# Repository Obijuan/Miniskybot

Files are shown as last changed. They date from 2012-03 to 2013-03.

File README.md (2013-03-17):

Miniskybot V2
===============

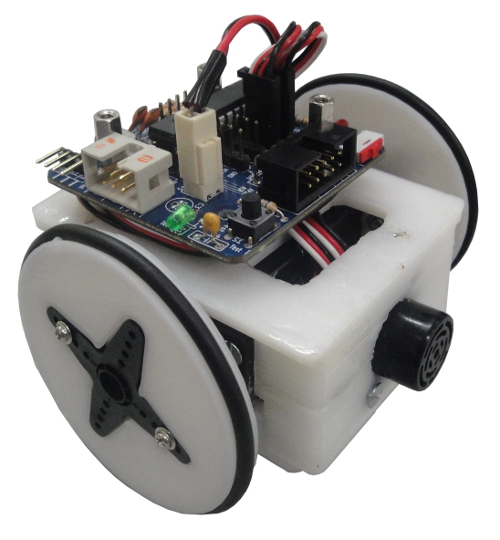
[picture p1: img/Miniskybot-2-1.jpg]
Miniskybot V2 with an skymega board Title


An open source 3D printable mobile robot ( **printbot** )

In this repository you can find the Miniskybot 2 or later
You can find more information (in spanish) in [this page](http://www.iearobotics.com/wiki/index.php?title=Miniskybot_2)

Features
--------
* Simplified chassis
* Marbel as cator wheel (thanks to sliptonic)
* Battery holder screwed to the chassis
* Compact and small
* 3 type of wheels, for the 3 different servo horns
* Electronics Compatible with [skymega](http://www.thingiverse.com/thing:14197) and [Arduino UNO](http://arduino.cc/en/Main/arduinoBoardUno) boards
  
License
=======

GPL license or Creative Commons Attribution-shareAlike  (Copyleft)

Authors
=======
* Juan Gonzalez-Gomez
* Andres Prieto-Moreno
* Miguel Angel de Frutos
* Antonio Barrientos

Credits
=======
* Alberto Valero
* Mohamed Abderrahim
* Sliptonic (for the Ball caster, derived from http://www.thingiverse.com/thing:13782)

Miniskybot V1
===========

For the miniskybot 1 go to the following links:

* http://www.iearobotics.com/wiki/index.php?title=Mini-Skybot_v1.0 (spanish)
* Thingiverse: http://www.thingiverse.com/thing:7989
* SVN repo: http://svn.iearobotics.com/Mini_Skybot/v1.0/

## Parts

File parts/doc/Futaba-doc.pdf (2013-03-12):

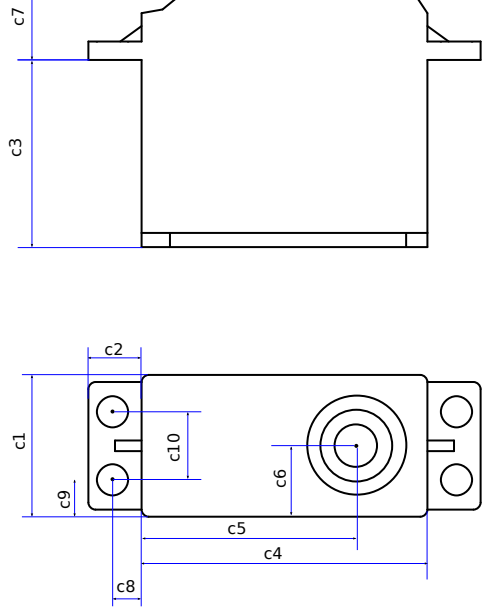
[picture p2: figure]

c7 = 11.6

c1= 20
c2=7.5
c3=26.4
c4=40.3
c5=30.3

c6=10

c8=4.1
c9=5.2
c10=9.6

### Futaba 3003 Servo dimensions

### Data needed for building the Miniskybot 2

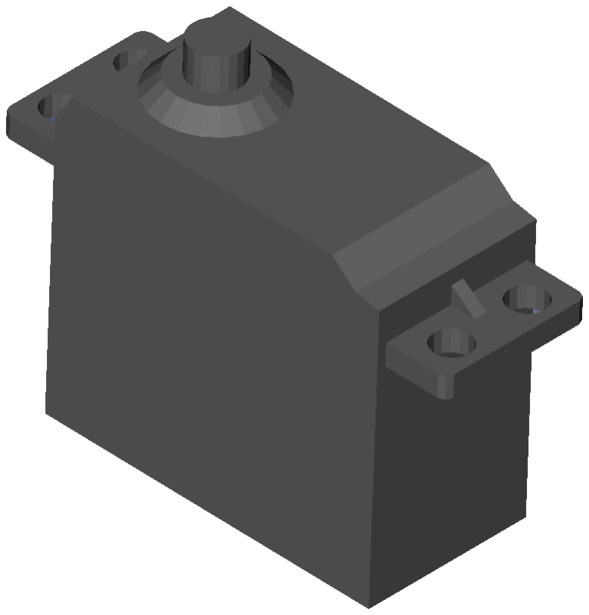
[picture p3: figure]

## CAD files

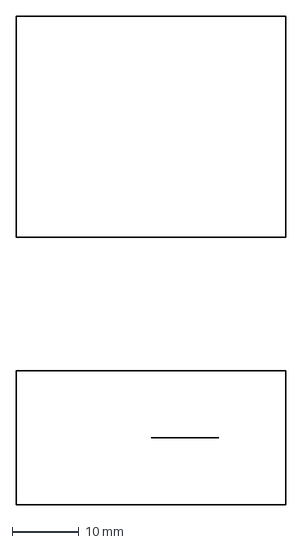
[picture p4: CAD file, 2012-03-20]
parts/futaba3003/futaba-main.dxf
40.3 x 73.0 mm

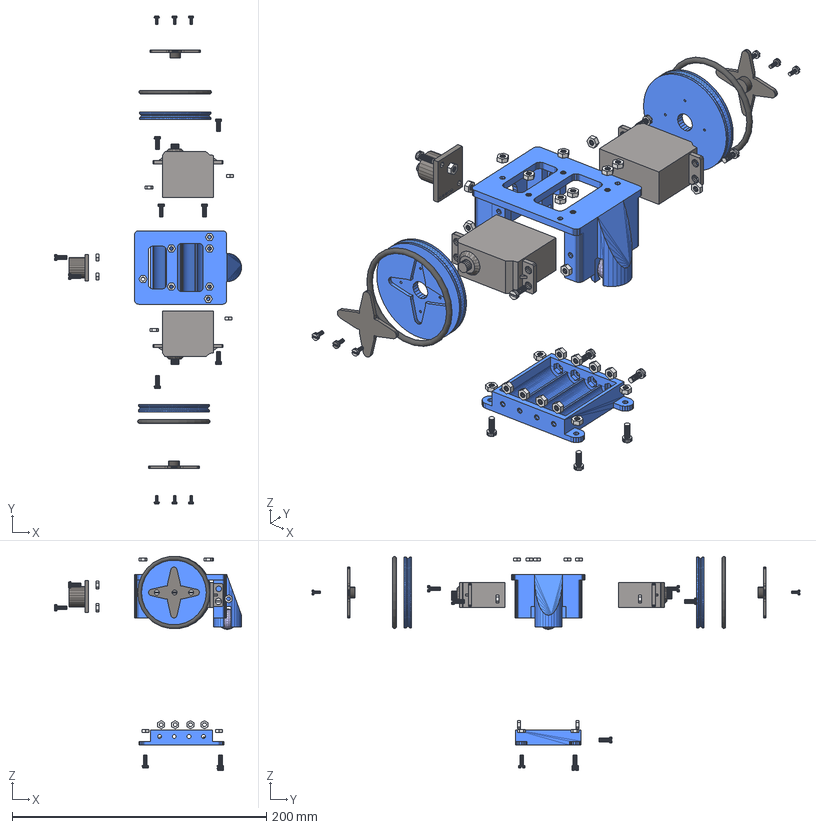
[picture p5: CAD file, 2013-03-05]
parts/Freecad/Mini-skybot-v2-exploded_view_drawing.fcstd
147.2 x 383.5 x 168.3 mm
Horn006
Bolt_wheel_007
Bolt_wheel_008
Bolt_wheel_009
Servo_wheel_4_arm_horn004
Goma-rueda1
horn005
Bolt_wheel_011
Bolt_wheel_010
Bolt_wheel_012
Goma-rueda2
Servo_wheel_4_arm_horn003
Right-servo001
Left-servo001
Bolt_011
Bolt_012
Bolt_013
Bolt_014
Bolt_015
Bolt_016
Bolt_017
Bolt_018
Bolt_019
Bolt_020
Nut_027
Nut_028
Nut_029
Nut_030
Nut_031
Nut_032
Nut_033
Nut_034
Battery_holder001
Nut_035
Nut_036
Nut_037
Nut_038
Nut_039
Nut_040
Nut_041
Nut_042
Nut_043
Nut_044
Nut_045
Nut_046
Nut_047
Nut_048
Nut_049
chassis002
marbel002
bolt_013
bolt_014
Nut_050
Nut_051
Fake_ultrasound001

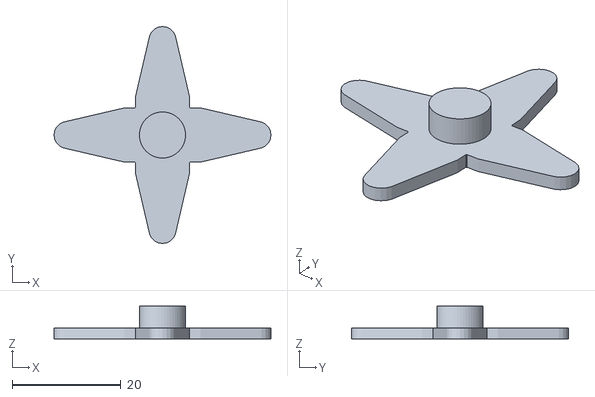
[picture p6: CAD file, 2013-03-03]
parts/Freecad/non-printable/stl/horn4.stl
40.0 x 40.0 x 6.00

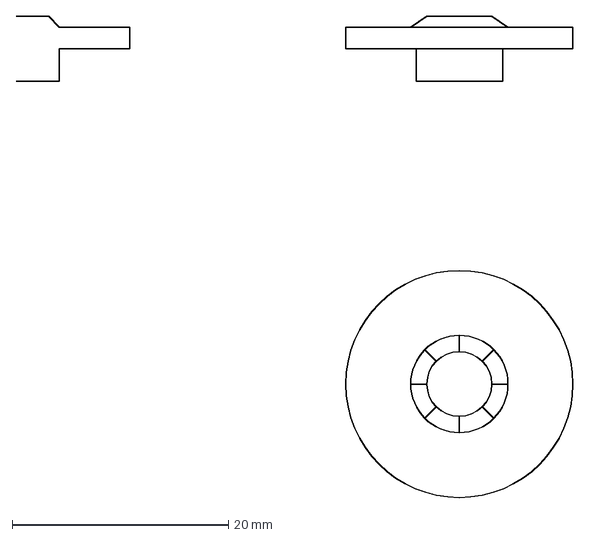
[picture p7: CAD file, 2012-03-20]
parts/futaba3003/futaba-plate.dxf
51.5 x 44.5 mm

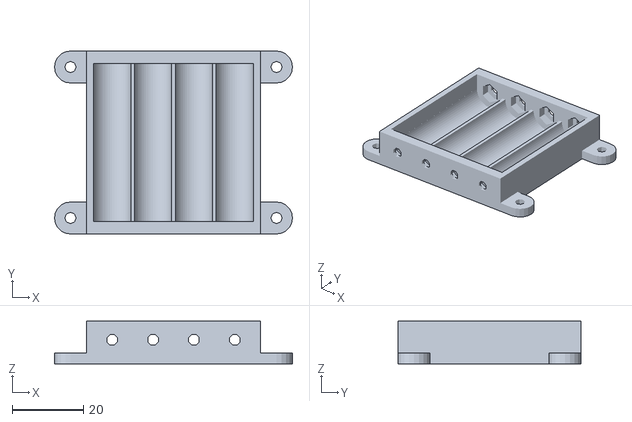
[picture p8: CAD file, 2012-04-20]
parts/STL/battery_holder.stl
67.0 x 51.5 x 12.0

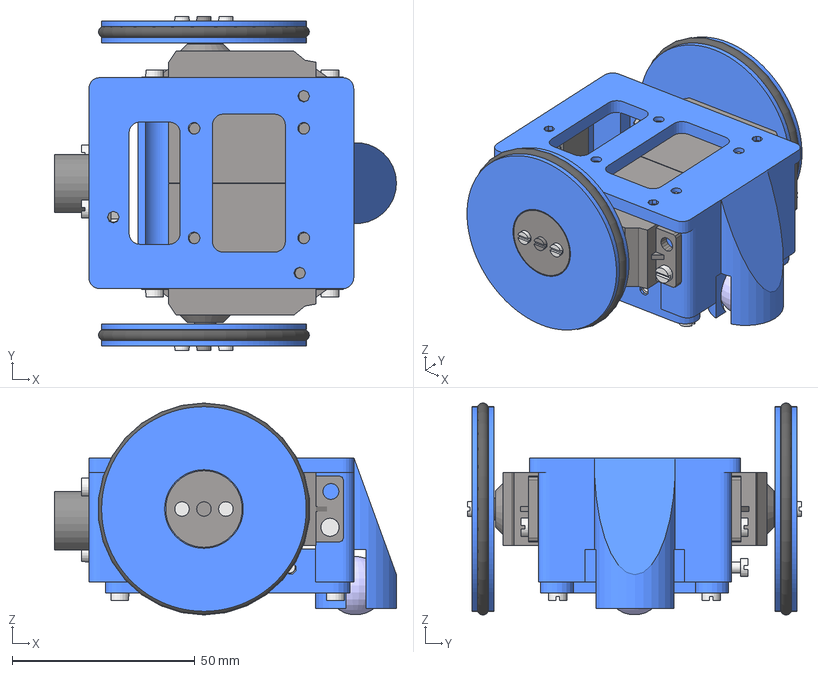
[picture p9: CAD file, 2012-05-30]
parts/Freecad/Mini-skybot-v2.fcstd
93.6 x 91.5 x 58.0 mm
Ruedas-skybot
Ruedas-skybot1
goma-rueda
goma-rueda1
futaba-plate
futaba-plate1
bolt_wheel_1
bolt_wheel_2
bolt_wheel_3
bolt_wheel_4
bolt_wheel_5
bolt_wheel_6
right-servo
left-servo
bolt_07
bolt_08
bolt_09
bolt_10
battery_holder
bolt_03
nut_16
nut_17
nut_18
nut_19
nut_20
nut_21
nut_22
nut_23
bolt_01
bolt_02
bolt_04
bolt_05
bolt_06
chassis
nut_01
nut_02
nut_03
nut_04
nut_5
nut_6
nut_7
nut_8
nut_9
nut_10
nut_11
nut_12
nut_13
nut_14
nut_15
marbel
fake_ultrasound
nut_24
nut_25
bolt_11
bolt_12

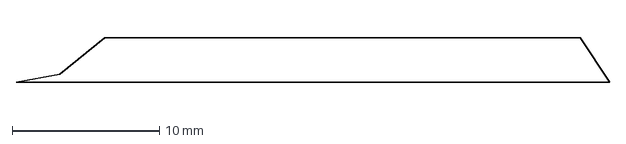
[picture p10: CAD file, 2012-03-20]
parts/futaba3003/futaba-top.dxf
40.3 x 3.00 mm

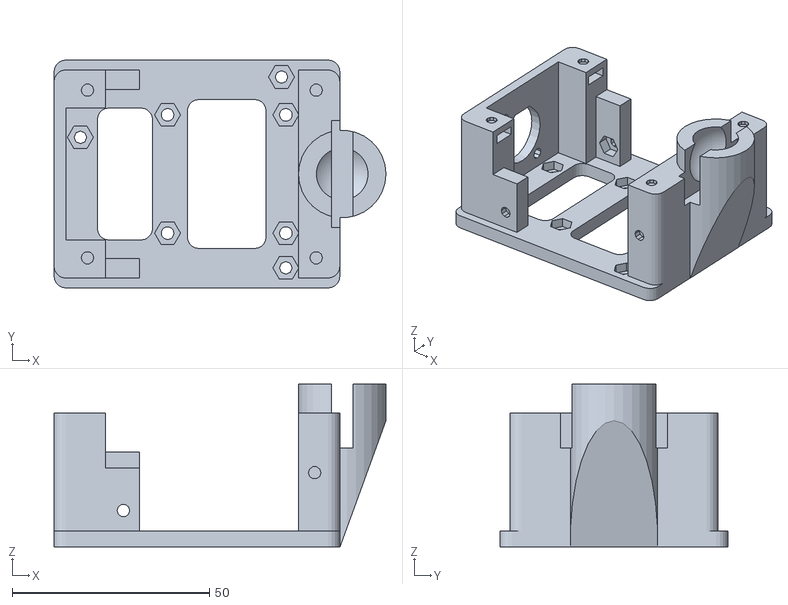
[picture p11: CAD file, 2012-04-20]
parts/STL/chassis.stl
84.2 x 57.8 x 41.3

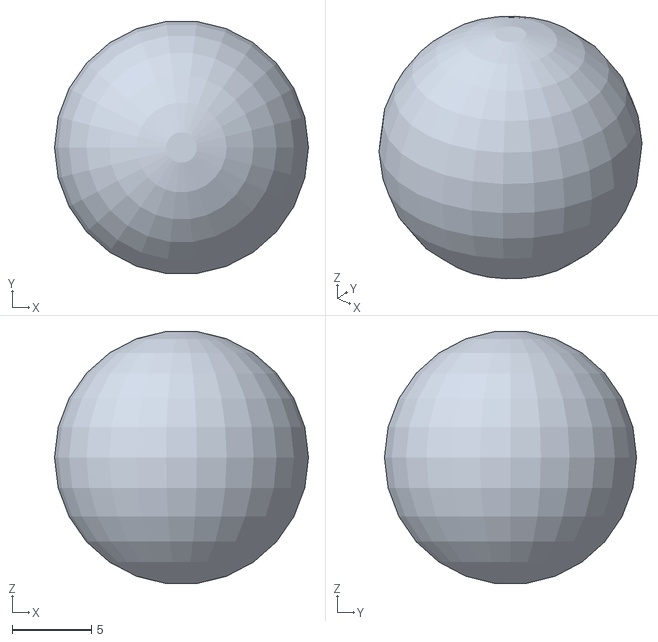
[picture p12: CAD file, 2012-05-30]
parts/Freecad/non-printable/stl/marbel.stl
16.0 x 15.9 x 15.9

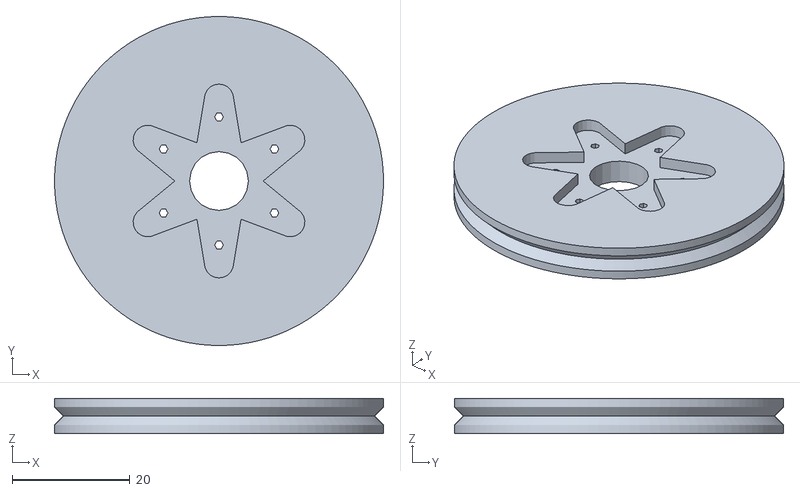
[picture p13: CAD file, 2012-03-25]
parts/STL/Servo-wheel-6-arm-horn.stl
56.0 x 56.0 x 6.00

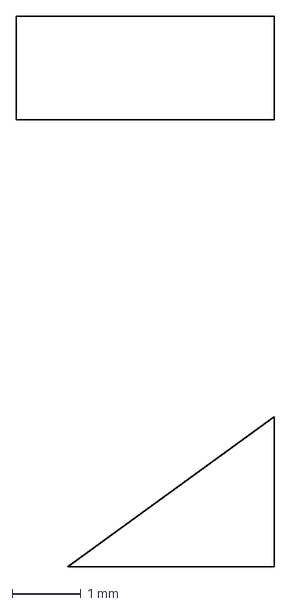
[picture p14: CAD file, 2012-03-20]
parts/futaba3003/futaba-ears2.dxf
3.75 x 8.00 mm

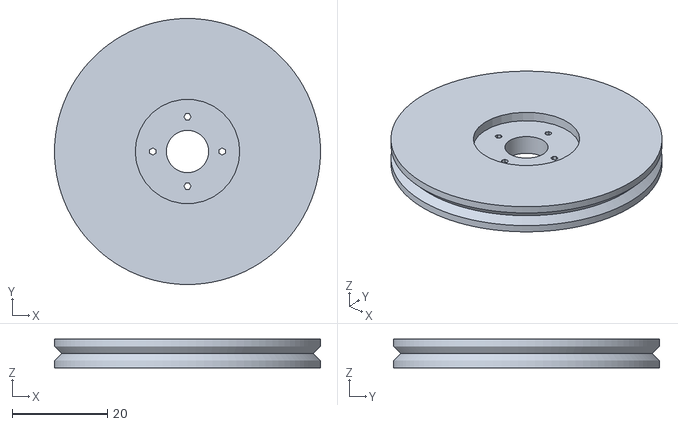
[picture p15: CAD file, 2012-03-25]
parts/STL/Servo-wheel-rounded-horn.stl
56.0 x 56.0 x 6.00

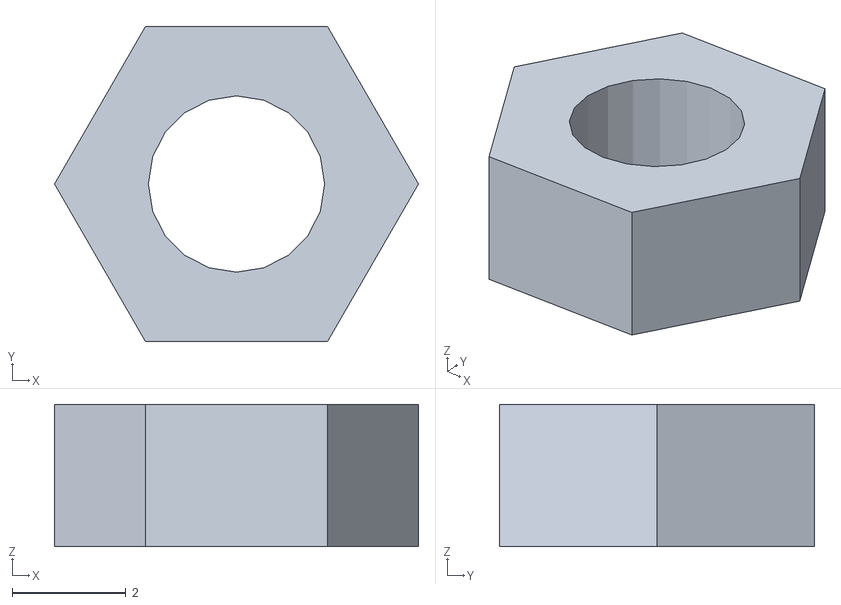
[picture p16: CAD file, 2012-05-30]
parts/Freecad/non-printable/stl/o-ring-wheel.stl
6.40 x 5.54 x 2.50

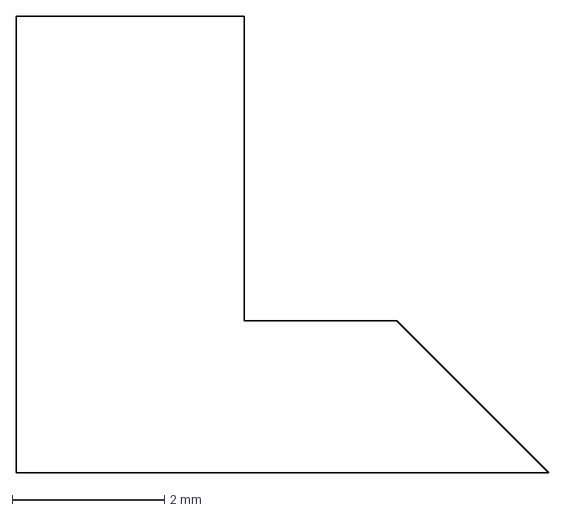
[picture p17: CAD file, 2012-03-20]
parts/futaba3003/Futaba-shaft.dxf
7.00 x 6.00 mm

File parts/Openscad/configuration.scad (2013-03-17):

//------------------------------------
//-- Miniskybot 2 configuration file
//------------------------------------

//-- drills
drill_M3 = 3.2;

//-- captive Nuts
nut_h = 2.6;
nut_radius = 6.6/2;

//------------------------------------------------
//-- Servo parameters
//-- See the doc/futaba-doc.pdf file
//------------------------------------------------
//-- Servo futaba 3003 dimensions
servo_c1 = 20;
servo_c2 = 7.5;
servo_c3 = 26.4;
servo_c4 = 40.3;
servo_c5 = 30.3;
servo_c6 = 10;
servo_c7 = 11.6;
servo_c8 = 4.1;
servo_c9 = 5.2;
servo_c10 = 9.6;

//-------------------------------------------
//-- Battery holder parameters
//-- See the doc/battery_holder-doc.pdf file
//-------------------------------------------
battery_c1 = 49;
battery_c2 = 51.5;
battery_c3 = 12;
battery_ear_diam = 9;
battery_ear_h = 3;
battery_top_gap = 1;  
//-- Real battery height whith batteries inserted
battery_height = battery_c3 + battery_top_gap;

//-------------------------------------------------
//-- Wheels parameters. 
//-- See the doc/Servo-wheels-doc.pdf
//------------------------------------------------
wheel_or_idiam = 50;                   //-- O-ring inner diameter
wheel_or_diam = 3;                     //-- O-ring section diameter
wheel_height = 2*wheel_or_diam+0;     //-- Wheel height: change the 0 for 
                                      //-- other value (0 equals minimun height)
                                      
//-- Wheel diameter is calculated from the o_ring                                      
wheels_diam = wheel_or_idiam + 2*wheel_or_diam;
wheel_gap = 1;  //-- For the final view. space between servo and wheel


//-------------------------------------------------
//-- Chassis (see doc/chassis-doc.pdf)
//-------------------------------------------------

robot_height = 47;

//-------- Rear part parameters ------------
rear_c1 = servo_c2 + 3;
rear_c2 = servo_c3*2;
rear_c3 = servo_c1 + battery_height -battery_ear_h;
rear_edge_rad = 3;

//-- Ball caster parameters
WallThickness = 2.25; //thickness of the retaining wall
BallSize = 16.4;  //diameter of  your ball bearing.
Airgap = .65;  // Gap between ball and wall  
BallProtrude = .35; //percentage of ball radius sticking out 
ball_caster_height = robot_height-(BallSize*BallProtrude);

//-- Front part parameters
front_c1 = battery_ear_diam + 4;
front_thickness = 3;
frame_corner_radius = 3;


//-- Top plate
top_plate_c1 = battery_c1 + front_c1 + rear_c1;
top_plate_c2 = rear_c2+5;
top_plate_thickness = 4;


//-- Skymega board dimensions
skymega_lx = 51.4;
skymega_ly = 51.4;
skymega_width=3;
skymega_dx = 15;
skymega_dy = 15;

//-- ultrasounds
ultrasound_hole = 16.5;
ultrasound_base_lx = 24+1;
ultrasound_base_ly = 20+1;
ultrasound_base_lz = 3;
ultrasound_length = 12.5;
ultrasound_drill_1 = [-9,7,0];
ultrasound_drill_2 = [9,-8,0];

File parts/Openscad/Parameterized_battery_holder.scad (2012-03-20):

/***************************************************************
 Parameterized Battery pack with electrical connections
  (c) 2010 Juan Gonzalez-Gomez (Obijuan) juan@iearobotics.com
   This design is derived from the Battery comparment generator
   (c) Nikolaus Gradwohl (guru (at) local-guru.net)
    http://www.thingiverse.com/thing:5051
Other contributors:
  * Chris Thompson (http://eagleapex.com/): Connection in series along the case
 -----------------------------------------------------------
 The nuts (two per battery) are embedded into the battery pack. 
 The screws (two per battery) are inserted from the outside and
 touch the batteries.
-----------------------------------------------------------
GPL LICENCE
****************************************************************/
include <configuration.scad>
use <functions.scad>

/***************************************************/
/* Battery holder. Parameters                      */
/* -size: battery size. It can be:                 */
/*    0 for AA, 1 for AAA, 2 for C and 3 for D     */
/* -num: Number of batteries                       */
/***************************************************/
module battery_holder(size=0, num=4)
{
   //-- Battery sizes
  batteries = [
    [ 10.5,44.5 ],  //-- AAA
    [14.5, 50.5],   //-- AA size
    [ 26.2, 50 ],   //-- C
    [ 34.2, 61.5 ], //-- D
  ];

  //--default value
  typ=batteries[size];

  //---------------------------------
  //-- Battery pack parameters
  //-- Can be set by the user
  //---------------------------------

  //-- Battery pack thickness
  bottom_thick=1.5;
  fr_thick=3.5;    //-- Front and rear parts
  side_thick=2;    //-- Side part

  //-- Distance beween batteries
  distance_bat=1;

  //-- Battery dimensions: width, height and length. Change ser for batteries in series along the case.  

  ser=1;
  w=typ[0];
  h=w;
  l=typ[1]*ser;

  //-- Dimensions of the inner part of the compartiment
  ip_l = l;
  ip_w = w + (w+distance_bat)*(num-1);
  ip_h = h;

  //-- Dimensions of the mother cube
  mc_l = ip_l+2*fr_thick;
  mc_w = ip_w+2*side_thick;
  mc_h = ip_h+bottom_thick;

  //-- The process of building the battery pack is just substracting
  //-- things to the mother cube
  translate([0,0,bottom_thick/2])
  rotate([0,0,90])
  difference() {
    //-- The mother cube
     translate([0,0,-bottom_thick/2])
      cube(size=[mc_l, mc_w, mc_h],center=true);

    //-- Array of batteries
    translate([0,0,h/2])
    cube(size=[ip_l,ip_w,ip_h],center=true);

    translate([0,-mc_w/2+w/2+side_thick,0])
    for ( i = [0:num-1] ) {

      translate([0,i*(w+distance_bat),0])
      union() {
        translate([0,0,h/2])
           cube(size=[l,w,h],center=true);

        rotate([0,90,0])
          cylinder(r=w/2, h=l-0.01, center=true, $fn=50); 
      }
    }

    //-- Array of contacts
    translate([0,-mc_w/2+w/2+side_thick,0])
    for ( i = [0:num-1] ) {
      //-- Drills
      translate([0,i*(w+distance_bat),0])
      rotate([0,90,0])
      rotate([0,0,45/2])
      cylinder(center=true,h=l+20, r=drill_M3/2, $fn=8);

      //-- Room for the embedded nuts
      translate([0,i*(w+distance_bat),0])
      rotate([0,90,0]) 
      cylinder(h=l+2*nut_h, r=nut_radius, $fn=6, center=true);
    }
  
  }
}

//-- Default battery holder
battery_holder();

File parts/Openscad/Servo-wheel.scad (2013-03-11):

//-------------------------------------------------------------
//-- Servo wheel
//-- (c) Juan Gonzalez (obijuan) juan@iearobotics.com
//-- March-2012
//-------------------------------------------------------------
//-- Wheel for mobile robots, drived by Futaba 3003 servos
//-------------------------------------------------------------
include <configuration.scad>


//-- Parameters common to all horns
horn_drill_diam = 1.5;
horn_height = 6;        //-- Total height: shaft + plate
horn_plate_height = 2;  //-- plate height

//-- Futaba 3003 servo rounded horn parameters
rh_diam1 = 8.5;  //-- Rounded horn small diameter
rh_diam2 = 21.5; //-- Rounded horn big diameter
rounded_horn_drill_distance = 7.3;

//-- Futaba 3003 horn drills


//-- Futaba 3003 4-arm horn parameters
a4h_end_diam = 5;
a4h_center_diam = 10;
a4h_arm_length = 15;
a4h_drill_distance = 13.3;


//-- Futaba 3003 6-arm horn parameters
a6h_end_diam = 5;
a6h_center_diam = 10;
a6h_arm_length=10;
a6h_arm_base_diam=7.5;
a6h_drill_distance = 10.9;


//-------------------------------------------------------
//--- Parameters:
//-- or_idiam: O-ring inner diameter
//-- or_diam: O-ring section diameter
//-- h: Height of the wheel
//--
//--  Module for generating a raw wheel, with no drills
//--  and no servo horn
//-------------------------------------------------------
module raw_wheel(or_idiam=50, or_diam=3, h=6)
{
   //-- Wheel parameters
   r = wheels_diam / 2;   //-- Radius

  //-- Temporal points
  l = or_diam*sqrt(2)/2;

  difference() {
    //-- Body of the wheel
    cylinder (r=r, h=h, $fn=100,center=true);

    //--  wheel's inner section
    rotate_extrude($fn=100)
      translate([r-or_diam/2,0,0])
      polygon( [ [0,0],[l,l],[l,-l] ] , [ [0,1,2] ]);
  }
}

//--------------------------------------------------------------
//-- Generic module for the horn's drills
//-- Parameters:
//--  d = drill's radial distance (from the horn's center)
//--  n = number of drills
//--  h = wheel height
//--------------------------------------------------------------
module horn_drills(d,n,h)
{
  union() {
    for ( i = [0 : n-1] ) {
        rotate([0,0,i*360/n])
        translate([0,d,0])
        cylinder(r=horn_drill_diam/2, h=h+10,center=true, $fn=6);  
      }
  }
}

//-----------------------------------------
//-- Futaba 3003 horn4 arm
//-- This module is just one arm
//-----------------------------------------
module horn4_arm(h=5)
{
  translate([0,a4h_arm_length-a4h_end_diam/2,0])
  //-- The arm consist of the perimeter of a cylinder and a cube
  hull() {
    cylinder(r=a4h_end_diam/2, h=h, center=true, $fn=20);
    translate([0,1-a4h_arm_length+a4h_end_diam/2,0])
      cube([a4h_center_diam,2,h],center=true);
  }
}

//-----------------------------------------
//-- Futaba 3003 horn6 arm
//-- This module is just one arm
//-----------------------------------------
module horn6_arm(h=5)
{
  translate([0,a6h_arm_length-a6h_end_diam/2,0])
  //-- The arm consist of the perimeter of a cylinder and a cube
  hull() {
    cylinder(r=a6h_end_diam/2, h=h, center=true, $fn=20);
    translate([0,-a6h_arm_length+a6h_end_diam/2,0])
    cube([a6h_arm_base_diam,0.1,h],center=true);
  }
}


//-------------------------------------------
//-- Futaba 3003 4-arm horn
//-------------------------------------------
module horn4(h=5)
{
  union() {
    //-- Center part (is a square)
    cube([a4h_center_diam+0.2,a4h_center_diam+0.2,h],center=true);

    //-- Place the 4 arms in every side of the cube
    for ( i = [0 : 3] ) {
      rotate( [0,0,i*90])
      translate([0, a4h_center_diam/2, 0])
      horn4_arm(h);
    }
  }

}

//-------------------------------------------
//-- Futaba 3003 6-arm horn
//-------------------------------------------
module horn6(h=5)
{
  union() {
    //-- The center part is a cylinder
    cylinder(r=15/2,h=h,center=true);

    //-- Place the 6 arms rotated 60 degrees
    for ( i = [0 : 5] ) {
      rotate( [0,0,i*60])
      translate([0, 15/2*cos(30), 0])
      horn6_arm(h);
    }
  }
}


//-------------------------------------------------------
//--  A Wheel for the futaba 3003 rounded horns
//--------------------------------------------------------
module Servo_wheel_rounded_horn()
{
  difference() {
      raw_wheel(or_idiam=wheel_or_idiam, or_diam=wheel_or_diam, h=wheel_height);

      //-- Inner drill
      cylinder(center=true, h=2*wheel_height + 10, r=rh_diam1/2+0.2,$fn=100);

      //-- Carved circle for the Futaba rounded horn
      translate([0,0,-wheel_height/2+horn_height-horn_plate_height]) 
       cylinder(r=rh_diam2/2+0.25, h=2*wheel_height+10,$fn=30);

      //-- small drills for the rounded horn
      horn_drills(d=rounded_horn_drill_distance, n=4, h=wheel_height);
  }

}

//-------------------------------------------------------
//--  A Wheel for the futaba 3003 4-arm horns
//--------------------------------------------------------
module Servo_wheel_4_arm_horn()
{
  difference() {
      raw_wheel(or_idiam=wheel_or_idiam, or_diam=wheel_or_diam, h=wheel_height);

      //-- Inner drill
      cylinder(center=true, h=2*wheel_height + 10, r=a4h_center_diam/2,$fn=20);

      //-- substract the 4-arm servo horn
      translate([0,0,horn_height-horn_plate_height])
        horn4(h=wheel_height);

      //-- Horn drills
      horn_drills(d=a4h_drill_distance, n=4, h=wheel_height);

  }
}

//-------------------------------------------------------
//--  A Wheel for the futaba 3003 6-arm horns
//--------------------------------------------------------
module Servo_wheel_6_arm_horn()
{
  difference() {
      raw_wheel(or_idiam=wheel_or_idiam, or_diam=wheel_or_diam, h=wheel_height);

       //-- Inner drill
      cylinder(center=true, h=2*wheel_height + 10, r=a6h_center_diam/2,$fn=20);

      //-- substract the 6-arm horn
      translate([0,0,horn_height-horn_plate_height])
      horn6(h=wheel_height);

      //-- Horn drills
      horn_drills(d=a6h_drill_distance, n=6, h=wheel_height);
  }
}


//-- Test!

//Servo_wheel_rounded_horn();
//translate([wheel_or_idiam+10,0,0]) 
Servo_wheel_4_arm_horn();

//translate([-wheel_or_idiam-10,0,0]) Servo_wheel_6_arm_horn();


/*-- Calculating the top view (for the documentation) 
projection(cut=false)
Servo_wheel_4_arm_horn();
*/


/*-- Horn6. Used in the freecad drawing
translate([0, 0, 4/2 + 2/2],$fn=50)
cylinder(r=8.5/2, h=4, center=true);
horn4(h=2);
*/

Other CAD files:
parts/STL/Servo-wheel-4-arm-horn.stl
parts/futaba3003/futaba-doc1.dxf
parts/futaba3003/futaba.stl
parts/futaba3003/futaba-ears.dxf
parts/futaba3003/futaba.scad
parts/Freecad/non-printable/bolt.scad
parts/Freecad/non-printable/marbel.scad
parts/Freecad/non-printable/nut.scad
parts/Freecad/non-printable/o-ring.scad
parts/Freecad/non-printable/stl/bolt_M3.stl
parts/Openscad/battery_holder.scad
parts/Openscad/fake_ultrasound.scad
parts/Openscad/functions.scad
parts/Openscad/main.scad
parts/futaba3003/futaba_plate.scad

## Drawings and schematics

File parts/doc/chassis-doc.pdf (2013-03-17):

## Miniskybot 2.0 Chassis dimensions Rear_c3

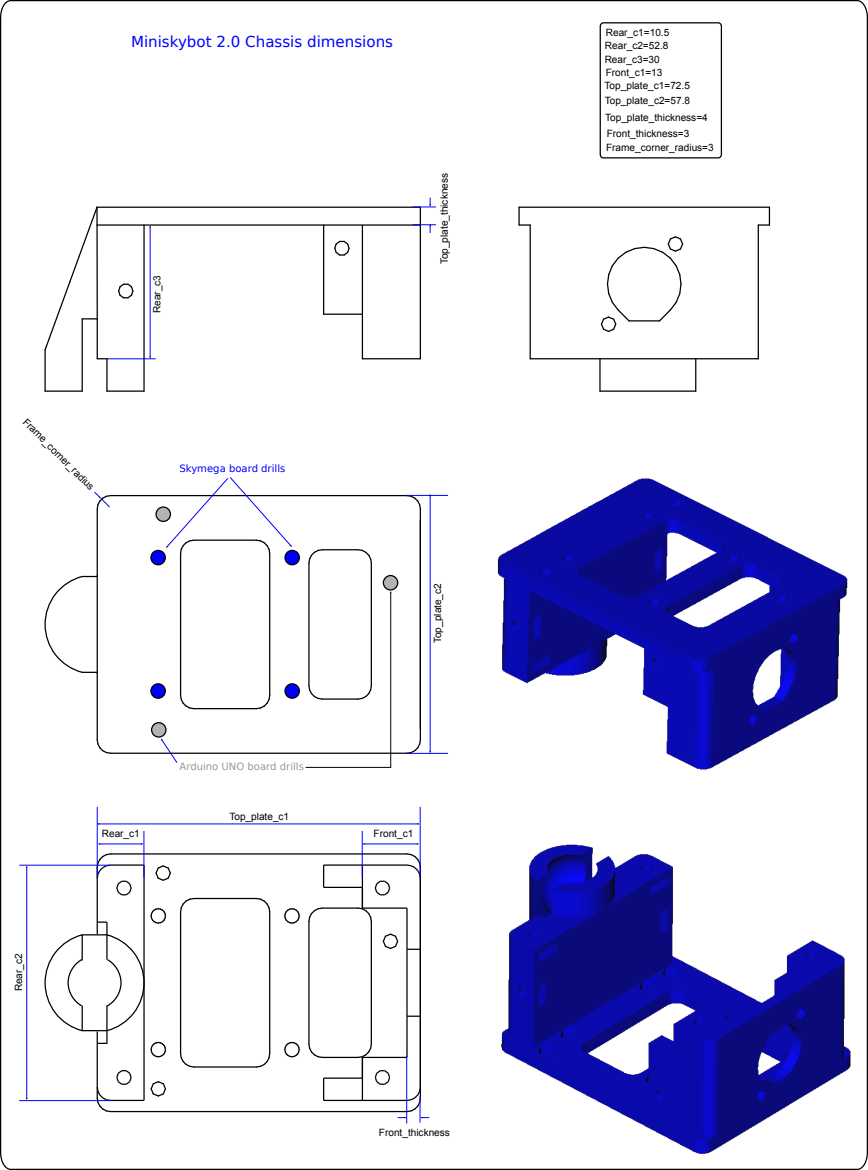
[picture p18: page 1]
Rear_c1; Rear_c2; Front_c1; Top_plate_c1; Top_plate_c2 Top_plate_thickness; Front_thickness; Frame_corner_radius; Rear_c1=10.5 Rear_c2=52.8; Front_c1=13 Top_plate_c1=72.5 Top_plate_c2=57.8; Top_plate_thickness=4 Front_thickness=3 Frame_corner_radius=3; Rear_c3=30

Skymega board drills

Arduino UNO board drills

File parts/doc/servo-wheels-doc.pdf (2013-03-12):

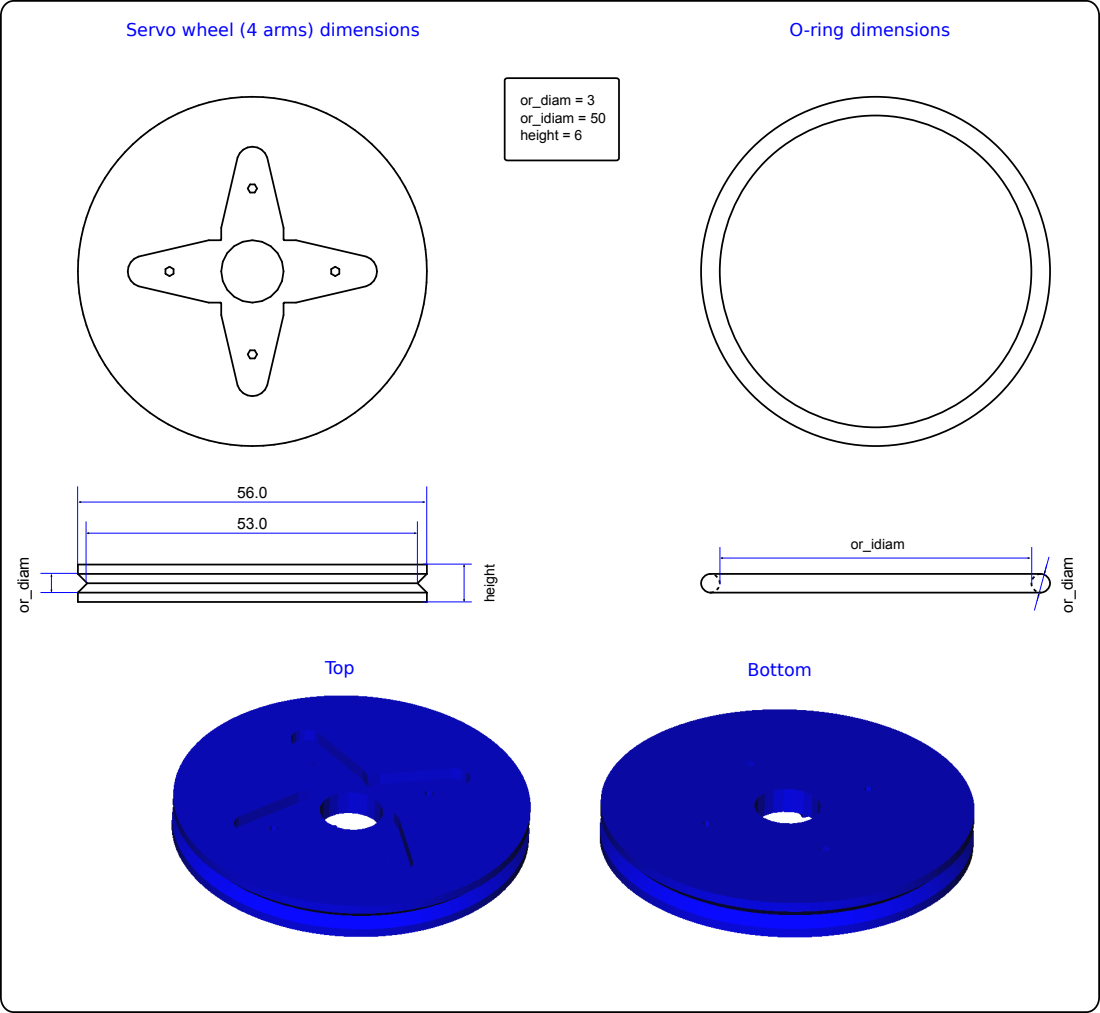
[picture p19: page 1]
Servo wheel (4 arms) dimensions; O-ring dimensions height; or_diam; or_idiam; or_diam = 3 or_idiam = 50 height = 6; Top; Bottom

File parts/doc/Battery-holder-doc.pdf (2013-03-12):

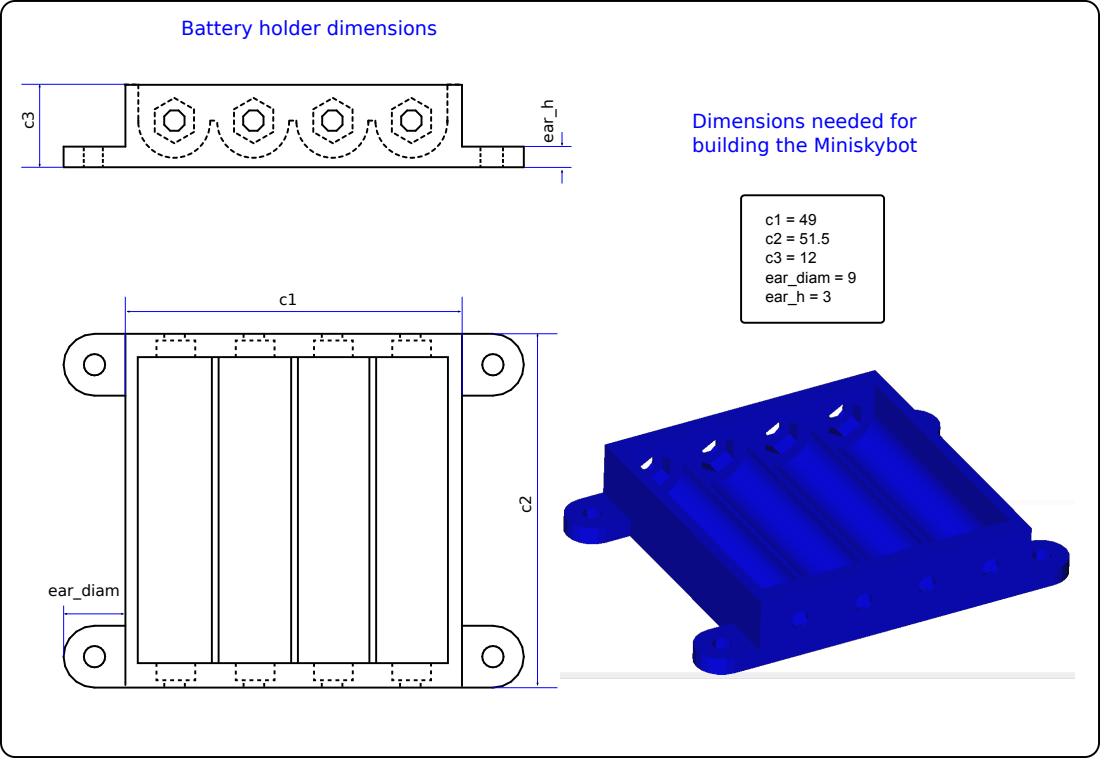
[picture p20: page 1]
c1 = 49 c2 = 51.5 c3 = 12 ear_diam = 9 ear_h = 3; ear_h; ear_diam

Battery holder dimensions

Dimensions needed for
building the Miniskybot

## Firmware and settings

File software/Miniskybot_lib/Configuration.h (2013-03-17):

//-- Configuration.h

//-- Distance between wheels
#define DIST_WHEEL 8.5

//-- Max number of elements:
#define MAX_MOTORS 2 //-- Not recommended to change this, as the Miniskybot code has been developed for a 2-wheel robot
#define MAX_SENSORS_US 2
#define MAX_SENSORS_IR 1

//-- Table containing all the alpha and beta parameters pairs for all IR sensors
const float CALIBRATION_PARAM[MAX_SENSORS_IR][2] = {
	{ 1, 1 } //-- Alpha1, Beta1
};

//-- Types of sensors:
#define IR 0 		//-- Infrared sensor 
#define US 1		//-- Ultrasound sensor, generic
#define US_3PIN 1 	//-- Ultrasound sensor, 3 pin
#define US_4PIN 2 	//-- Ultrasound sensor, 4 pin


//-- Table containing all the pairs (velocity/value)
//-- Must be ordered from higher to lower values
#define NUM_VALUES 13
const float VELOCITY_TABLE[NUM_VALUES][2] = {
	{ 14.5, 255 },
	{ 12.5, 235},
	{ 12.0, 215},
	{ 12.0, 195},
	{ 11.0, 175},
	{ 10.0, 155},
	{  9.0, 135},
	{  7.0, 115},
	{  6.0,  95},
	{  4.0,  75},
	{  3.0,  65},
	{  2.0,  55},
	{  0.0,   0}
};

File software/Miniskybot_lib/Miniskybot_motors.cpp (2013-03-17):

//------------------------------------------------------------------------------
//------------------------------------------------------------------------------
//-- Miniskybot library
//------------------------------------------------------------------------------
//-- Simplify working and programming a Miniskybot (or similar) robot by using
//-- this library.
//--
//-- This library takes charge of controlling the motors by means of a L293 dual
//-- H-bridge circuit, but extra functions could be added to work with more types
//-- of motors.
//--
//-- For more info, read README
//------------------------------------------------------------------------------
//-- Author:
//-- David Estévez-Fernández, Jun 2012
//-- GPL license
//------------------------------------------------------------------------------
//-- Requires a Miniskybot  robot, design by Juan González-Gómez (Obijuan):
//-- https://github.com/Obijuan/Miniskybot
//------------------------------------------------------------------------------


#include "Miniskybot_motors.h"


//-------------------------------------------------------------------------
//-- Constructor
//-------------------------------------------------------------------------
//-- Arguments: pins conected to the H-bridge (left, right and chip enable)
//-------------------------------------------------------------------------

MotorL293::MotorL293( )
{
	_pinLeft = -1;
	_pinRight = -1;
	_pinEnable = -1;

	_speed = 0;
	_forward = true;
}


//--------------------------------------
//-- Initialize the motor object:
//--------------------------------------

void MotorL293::attach(int pinLeft, int pinRight, int pinEnable)
{
	//-- Save the pin configuration
	_pinLeft = pinLeft;
	_pinRight = pinRight;
	_pinEnable = pinEnable;

	//-- Set the pins as outputs
	pinMode( _pinLeft, OUTPUT);
	pinMode( _pinRight, OUTPUT);
	pinMode( _pinEnable, OUTPUT);

	//-- Put all pins at 0V (motor OFF)
	digitalWrite( _pinLeft, LOW);
	digitalWrite( _pinRight, LOW);
	digitalWrite( _pinEnable, LOW );
}


//---------------------------------------------------------
//-- Sets motor velocity to a value between 0 and 255.
//-- Sense is given by the sign of velocity.
//---------------------------------------------------------

void MotorL293::setVelocity( int velocity)
{
	//-- If pins are not assigned, don't execute any code
	if ( _pinLeft != -1 && _pinRight != -1 && _pinEnable != -1)
	{
		//-- Distinguish between forward / backwards movement
		if ( velocity >= 0 )
		{
			//-- Assign new values to variables:
			_speed = velocity;
			_forward = true;
		
			//-- Send the correct signals to the H-bridge:
			digitalWrite( _pinLeft, LOW);
			digitalWrite( _pinRight, HIGH);
		}
		else
		{
			//-- Assign new values to variables:
			_speed = -velocity;
			_forward = false;

			//-- Send the correct signals to the H-bridge:	
			digitalWrite( _pinLeft, HIGH);
			digitalWrite( _pinRight, LOW);
		}

		//-- Set speed:
		analogWrite(  _pinEnable, _speed);
	}
}


//---------------------------------------------------------
//-- Sets motor velocity to a value between 0 and 255.
//-- Sense is given explicitely by forward, velocity
//-- should be positive.
//---------------------------------------------------------

void MotorL293::setVelocity( int velocity, bool forward)
{
	//-- If pins are not assigned, don't execute any code
	if ( _pinLeft != -1 && _pinRight != -1 && _pinEnable != -1)
	{
		//-- Assign new values to variables:
		_speed = abs(velocity);		
		_forward = forward;
	
	
		//-- Send the correct signals to the H-bridge:
		if ( _forward )
		{				
			digitalWrite( _pinLeft, LOW);
			digitalWrite( _pinRight, HIGH);
		}
		else
		{
			digitalWrite( _pinLeft, HIGH);
			digitalWrite( _pinRight, LOW);
		}

		//-- Set speed:
		analogWrite(  _pinEnable, _speed);
	} 
}


//----------------------------------------------------
//-- Returns the value of the current velocity
//-- (not actual velocity, the one given by the user)
//----------------------------------------------------

int MotorL293::getVelocity()
{
	//-- Set the modulus:
	int velocity = _speed;
	
	//-- Set the sense:
	if ( !_forward) {velocity*=-1;}
	
	return velocity;
}



//----------------------------------------------------
//-- Just stops the motor
//----------------------------------------------------

void MotorL293::emergencyBrake()
{
	//-- Stop the motor
	digitalWrite( _pinEnable, LOW);	
	digitalWrite( _pinLeft, HIGH);
	digitalWrite( _pinRight, HIGH);
}

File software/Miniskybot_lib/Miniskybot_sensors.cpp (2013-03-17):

//------------------------------------------------------------------------------
//------------------------------------------------------------------------------
//-- Miniskybot library
//------------------------------------------------------------------------------
//-- Simplify working and programming a Miniskybot (or similar) robot by using
//-- this library.
//--
//-- This library takes charge of obtaining data of several sensors, such as IR 
//-- sensors or ultrasound sensors.
//--
//-- For more info, read README
//------------------------------------------------------------------------------
//-- Author:
//-- David Estévez-Fernández, Jun 2012
//-- GPL license
//------------------------------------------------------------------------------
//-- Requires a Miniskybot  robot, design by Juan González-Gómez (Obijuan):
//-- https://github.com/Obijuan/Miniskybot
//------------------------------------------------------------------------------


#include "Miniskybot_sensors.h"


//################################################################################
//################################################################################
//-- SensorIR members
//################################################################################
//################################################################################

//-- Constructor
SensorIR:: SensorIR() 
{
	_pin = -1; 
	_length = 0;
	_alpha = _beta = 1;
}

//-- Attach the sensor to a pin
void SensorIR::attach(int pin)	{_pin = pin;}
	
//-- Attach the sensor to a pin (with calibration)
void SensorIR::attach( int pin, float alpha, float beta)
{
	_pin = pin;
	calibrate( alpha, beta);
}


//-- Get the voltage measure from the arduino
float SensorIR::getValue()
{
	//-- If pin not assigned, return -1
	if (_pin != -1)
	{
		//-- Read the analog pin:
		int reading = analogRead(_pin);

		//-- Map the reading:
		float value = 5/1023.0*reading;

		//-- Return the value
		return value;
	}
	else
	{
		return -1;
	}
}


//-- Retuns the distance (cm) to the obstacle
float SensorIR::getLength()
{
	//-- If pin not assigned, return -1
	if (_pin != -1)
	{
		//-- Get the voltage reading:
		float value = getValue();

		//-- Convert the value to distance:
		float length = _alpha * pow(value/1000, -_beta);
	
		//-- Assing this value to the internal variable:
		_length = length;

		//-- return the length:
		return length;
	}
	else
	{
		return -1;
	} 
}


//-- Sets alpha and beta parameters of the sensor
void SensorIR::calibrate( float alpha, float beta)
{
	_alpha = alpha;
	_beta = beta;
}



//################################################################################
//################################################################################
//-- SensorUS members
//################################################################################
//################################################################################

//-- Constructor
SensorUS::SensorUS()	
{ 
	_length = 0; 
	_pin[0] = -1; 
	_pin[1] = -1; 
}

//-- Attach sensor to pin and setup
void SensorUS::attach( int pinSignal) //-- For 3-wire US sensors (single trigger/echo)
{
	_type = true;
	_pin[0] = pinSignal;
	_pin[1] = -1;
}


void SensorUS::attach( int pinTrigger, int pinEcho) //-- For 4-wire US sensor
{
	_type = false;
	_pin[0] = pinTrigger;
	_pin[1] = pinEcho;

	//-- Setup
	pinMode( _pin[0], OUTPUT); //-- Set trigger pin as output
	pinMode( _pin[1], INPUT); //-- Set echo pin as input
}


//-- Read distance:	
float SensorUS::getLength()
{
	//-- If pin not assigned, don't execute anything:
	if ( _pin[0] != -1)
	{
		//-- Different action for different sensors:
		if (_type)
		{
			//---------------------------------------------------------
			//-- This is performed for a 3-wire sensor
			//-- Based on:
			//-- http://www.arduino.cc/en/Tutorial/Ping
			//--------------------------------------------------

			int pin = _pin[0];
		
			//-- Set pin as output:
			pinMode( pin, OUTPUT);
	 
		  	//--Send the pulse:
			digitalWrite( pin, LOW);
			delayMicroseconds(2);
			digitalWrite( pin, HIGH);
			delayMicroseconds(10);
			digitalWrite( pin, LOW);
		
			//-- Set pin as input:
			pinMode( pin, INPUT);
		
			//-- Measure the response pulse:
			unsigned long duration = pulseIn( pin, HIGH);

			//--Calculating the distance:
			unsigned long length = duration / 29 / 2; //--Divide the echo by two, and by speed of sound 
		
			//-- Store the legth:
			_length = length;
		
			//-- Return the distance
			return length;	
		}
		else
		{
			//---------------------------------------------------------
			//-- This is performed for a 4-wire sensor
			//--
			//--
			//-- Based on:
			//-- Library for HC-SR04 Ultrasonic Ranging Module.library
			//-- Created by ITead studio. Apr 20, 2010.
	  		//-- http://www.iteadstudio.com
			//---------------------------------------------------------
		
			//-- Variables created for increased readability:
			int trigger = _pin[0], echo = _pin[1];

			//-- Obtaining the pulse length:

			//--Send the pulse:
			digitalWrite( trigger, LOW);
			delayMicroseconds(2);
			digitalWrite( trigger, HIGH);
			delayMicroseconds(10);
			digitalWrite( trigger, LOW);
		
			//-- Measure the response pulse:
			unsigned long duration = pulseIn( echo, HIGH);


			//--Calculating the distance:
			unsigned long length = duration / 29 / 2; //--Divide the echo by two, and by speed of sound 
		
			//-- Store the legth:
			_length = length;
		
			//-- Return the distance
			return length;		
		}
	}
}
	

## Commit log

2012-03-08 Initial files
    [functions.scad, main.scad]
2012-03-20 Futaba 3003 parts added
    [Futaba-shaft.dxf, futaba-doc1.dxf, futaba-doc2.dxf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]
2012-03-20 New battery holder with ears for screwing to the bottom of the robot
    [Parameterized_battery_holder.scad, battery_holder.scad]
2012-03-20 Servo-wheel imported from Miniskybot 1.0
    [Servo-wheel.scad]
2012-03-20 The Chasis is a release candidate. Ready for testing
    [functions.scad, main.scad]
2012-03-20 File moved to doc folder
    [futaba-doc2.dxf]
2012-03-20 The battery holder uses the global config file: configuration.scad
    [Parameterized_battery_holder.scad, battery_holder.scad, configuration.scad]
2012-03-20 the battery holder drills have =8
    [Parameterized_battery_holder.scad, battery_holder.scad, configuration.scad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]
2012-03-20 Some functions moved from main.scad to functions.scad
    [configuration.scad, functions.scad]
2012-03-20 Chassis validated
    [main.scad]
2012-03-20 Plans for the battery and rear parts (DXF)
    [battery_holder.dxf, rear_doc.dxf]
2012-03-22 New servo-wheels for the cross horn
    [Servo-wheel.scad]
2012-03-22 1- drills for the ultrasound added, 2-space for the battery holder wires, ball caster height incresed a little bit
    [configuration.scad, functions.scad, main.scad]
2012-03-23 New fake ultrasound added (not yet printed)
    [configuration.scad, fake_ultrasound.scad, main.scad]
2012-03-23 New wheel for the 6-arm servo horn
    [Servo-wheel.scad]
2012-03-24 New 6-arm-horn wheel
    [Servo-wheel.scad]
2012-03-25 Drills added to the Servo-wheel with rounded horn. Resize the horn diameter
    [Servo-wheel.scad]
2012-03-25 Servo-wheel code cleaned
    [Servo-wheel.scad]
2012-03-25 Fixed a small bug
    [Servo-wheel.scad]
2012-03-25 STL files for the servo-wheels added
    [Servo-wheel-4-arm-horn.stl, Servo-wheel-6-arm-horn.stl, Servo-wheel-rounded-horn.stl]
2012-04-20 STLs generated
    [battery_holder.stl, chassis.stl]
2012-05-30 Freecad drawing of the Miniskybot II
    [Mini-skybot-v2.fcstd, bolt.scad, bolt_M3.stl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]
2012-06-08 Motor library finished
2012-06-10 Sensor IR added
2012-06-10 Ultrasound sensor added
2012-06-10 Code debugged, errors corrected
    [Miniskybot_motors.cpp, Miniskybot_sensors.cpp, Miniskybot_sensors.h]
2012-06-11 Attach() member added
2012-06-12 Miniskybot class added
    [Configuration.h]
2012-06-12 Minor bugs fixed
    [Configuration.h]
2012-06-12 First example added
    [Configuration.h]
2012-06-13 Basic control of robot implemented
    [Configuration.h]
2013-03-03 All the meshes converted to solids
    [Servo-wheel.scad, horn4.stl]
2013-03-04 robot tyres changed by freecad torus
2013-03-05 Exploded view drawing, in Freecad
    [Mini-skybot-v2-exploded_view_drawing.fcstd]
2013-03-07 Futaba 3003 servo dimensions
2013-03-07 Futaba-doc2.dxf removed (svg version is used instead)
    [futaba-doc2.dxf]
2013-03-11 Battery holder documentation
    [battery_holder.scad]
2013-03-11 Servo Wheel
    [Servo-wheel.scad, configuration.scad, main.scad]
2013-03-12 Documentation of the battery holder
    [battery_holder.scad, configuration.scad]
2013-03-12 Documentation of the servo-wheels
2013-03-12 Batery holder doc migrated to svg format
    [battery_holder.dxf]
2013-03-17 Code cleant
    [configuration.scad, main.scad]
2013-03-17 Miniskybot chassis documentation added
2013-03-17 rear_doc.dxf deleted
    [rear_doc.dxf]
2013-03-17 Openscad files moved to openscad folder
    [Parameterized_battery_holder.scad, Servo-wheel.scad, battery_holder.scad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]
2013-06-03 Bug fixed: the castor wheel was by default shown with the % operator, so that the chassis was not correctly generated from the sources. Thanks to jrdeltoro and Carlosgs
    [main.scad]
2013-09-23 Miniskybot library moved to Miniskybot_lib folder
    [Configuration.h]
2013-10-22 Example for testing the robot motors
2013-10-22 Example for reading the digital ir sensors connected at pins A0 and A1
